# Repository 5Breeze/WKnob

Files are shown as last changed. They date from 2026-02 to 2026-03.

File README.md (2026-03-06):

<div style="font-family:sans-serif;max-width:900px;margin:auto;color:#333;line-height:1.7">

<div style="background:linear-gradient(135deg,#2a9d8f,#264653);padding:32px;border-radius:14px;color:white;text-align:center;margin-bottom:30px">
<h1 style="margin:0">WKnob Wireless Knob</h1>
  

<p style="opacity:0.9;margin-top:4px">BLE · HomeAssistant · BTHome · Encoder · Accelerometer Interaction</p>
</div>

<hr style="border:none;border-top:1px solid #ccc;margin:30px 0" />

<div style="background:#f8f9fa;padding:20px;border-radius:10px;border-left:5px solid #2a9d8f">
<h3 style="color:#2a9d8f;margin-top:0">Introduction</h3>
<p>I’ve long wanted to build a <strong>wireless knob controller</strong>, but off-the-shelf wireless buttons are already very cheap (around ¥10). DIYing a fully enclosed device didn’t seem cost-effective, so the idea was put on hold for a while.</p>
<p>Later, I noticed that <strong>wireless knobs with encoders are actually quite rare</strong>.</p>
<p>That gave me a new idea:<br />
• Add an <strong>encoder knob</strong>,<br />
• Include an <strong>accelerometer</strong>,<br />
• Unlock more <strong>interesting interactive features</strong>.</p>
<p>And so this project was born.</p>
</div>

<hr style="border:none;border-top:1px solid #ccc;margin:30px 0" />

<div style="background:#f8f9fa;padding:16px 18px;border-radius:10px;border-left:5px solid #2a9d8f">
<h3 style="color:#2a9d8f;margin:0 0 10px 0">Project Demo (click to view)</h3>
<div style="text-align:center">
<a href="https://www.bilibili.com/video/BV1ejPszpENa/" target="_blank">

</a>
</div>
</div>

<hr style="border:none;border-top:1px solid #ccc;margin:30px 0" />

<div style="border-left:4px solid #2a9d8f;padding:12px 16px;font-family:system-ui,sans-serif;max-width:800px">
<h3 style="margin:0 0 10px 0;color:#2a9d8f">Features Overview</h3>
<table style="width:100%;border-collapse:collapse;font-size:14px">
<thead>
<tr style="background:#f5f5f5">
<th style="padding:8px;border:1px solid #ddd;width:28%">Interaction</th>
<th style="padding:8px;border:1px solid #ddd">Function Description</th>
</tr>
</thead>
<tbody>
<tr>
<td style="padding:8px;border:1px solid #ddd">🔄 Encoder Knob</td>
<td style="padding:8px;border:1px solid #ddd">Rotation changes encoder value, range <b>-127 ~ +127</b>, supports cyclic counting</td>
</tr>
<tr>
<td style="padding:8px;border:1px solid #ddd">🔘 Single Click</td>
<td style="padding:8px;border:1px solid #ddd">Triggers <b>single-click event</b></td>
</tr>
<tr>
<td style="padding:8px;border:1px solid #ddd">🔘 Double Click</td>
<td style="padding:8px;border:1px solid #ddd">Triggers <b>double-click event</b></td>
</tr>
<tr>
<td style="padding:8px;border:1px solid #ddd">🔘 Triple Click</td>
<td style="padding:8px;border:1px solid #ddd">Triggers <b>triple-click event</b></td>
</tr>
<tr>
<td style="padding:8px;border:1px solid #ddd">⏳ Single Long Press</td>
<td style="padding:8px;border:1px solid #ddd">Triggers <b>single long-press event</b></td>
</tr>
<tr>
<td style="padding:8px;border:1px solid #ddd">⏳ Double Long Press</td>
<td style="padding:8px;border:1px solid #ddd">Triggers <b>double long-press event</b></td>
</tr>
<tr>
<td style="padding:8px;border:1px solid #ddd">⏳ Triple Long Press</td>
<td style="padding:8px;border:1px solid #ddd">Triggers <b>triple long-press event</b></td>
</tr>
<tr>
<td style="padding:8px;border:1px solid #ddd">📐 Hold & Keep Pressing</td>
<td style="padding:8px;border:1px solid #ddd">Enter special mode: read 3‑axis accelerometer data and reset encoder count</td>
</tr>
</tbody>
</table>
</div>

<hr style="border:none;border-top:1px solid #ccc;margin:30px 0" />

<div style="background:#f8f9fa;padding:20px;border-radius:10px;border-left:5px solid #2a9d8f">
<h3 style="color:#2a9d8f;margin-top:0">User Guide</h3>
<div style="background:#ffffff;border:1px solid #eee;padding:18px;border-radius:10px">
<h4>1️⃣ Firmware Flashing</h4>
<p>Flash firmware using the <strong>WCH_TOOL</strong> utility.</p>
<p>Features: simple operation | batch support | suitable for mass production</p>
<p>Firmware file is included in attachments.</p>
<div align="center" style="margin-top:15px">


</div>
</div>

<div style="background:#ffffff;border:1px solid #eee;padding:18px;border-radius:10px">
<h4>2️⃣ Use with HomeAssistant</h4>
<p>After flashing, add the device in <strong>Home Assistant (HA)</strong>.</p>
<p>The device is usually <strong>auto‑discovered</strong> under the name <strong>WKnob</strong>.</p>
<div align="center" style="margin-top:15px">


</div>
<p>Once added, you can view real‑time sensor data, create automations, and link with other HA devices.</p>
<div align="center" style="margin-top:15px">


</div>
</div>
</div>

<hr style="border:none;border-top:1px solid #ccc;margin:30px 0" />

<div style="background:#f8f9fa;padding:20px;border-radius:10px;border-left:5px solid #2a9d8f">
<h3 style="color:#2a9d8f;margin-top:0">Communication Mechanism</h3>
<p>Default strategy:<br />
Idle state: broadcast every 10 seconds<br />
Action triggered: broadcast 10 times per second<br />
Trigger state lasts <strong>2–5 seconds</strong>.<br />
Balances <strong>low power consumption</strong> and <strong>fast response</strong>.</p>
</div>

<hr style="border:none;border-top:1px solid #ccc;margin:30px 0" />

<div style="background:#f8f9fa;padding:18px 20px;border-radius:10px;border-left:4px solid #2a9d8f;font-family:system-ui,sans-serif;max-width:720px">
<h3 style="color:#2a9d8f;margin:0 0 12px 0">Related HA Projects</h3>
<ul style="list-style:none;padding:0;margin:0;line-height:1.6">
<li style="margin-bottom:10px"><b>🔵 HA BLE Door & Light Sensor / LMsensor</b><br /><a href="https://oshwhub.com/bitshen/bthome" style="color:#2a9d8f;text-decoration:none">https://oshwhub.com/bitshen/bthome</a></li>
<li style="margin-bottom:10px"><b>🟣 HA Voice Assistant / AIO</b><br /><a href="https://oshwhub.com/bitshen/esphome-ai" style="color:#2a9d8f;text-decoration:none">https://oshwhub.com/bitshen/esphome-ai</a></li>
<li style="margin-bottom:10px"><b>🟢 HA BLE Thermometer & Hygrometer</b><br /><a href="https://oshwhub.com/bitshen/shi-wai-wen-du-ji_copy" style="color:#2a9d8f;text-decoration:none">https://oshwhub.com/bitshen/shi-wai-wen-du-ji_copy</a></li>
<li style="margin-bottom:10px"><b>🟡 HA Desktop Sensor / CliQ</b><br /><a href="https://oshwhub.com/bitshen/guang-wen-ji-zhuo-mian-bai-jian" style="color:#2a9d8f;text-decoration:none">https://oshwhub.com/bitshen/guang-wen-ji-zhuo-mian-bai-jian</a></li>
<li style="margin-bottom:10px"><b>🟠 HA BLE Gateway VerA</b><br /><a href="https://oshwhub.com/bitshen/esp32-c3-mi-ni-lan-ya-wang-guan_copy" style="color:#2a9d8f;text-decoration:none">https://oshwhub.com/bitshen/esp32-c3-mi-ni-lan-ya-wang-guan_copy</a></li>
<li><b>🔷 HA BLE Gateway VerB</b><br /><a href="https://oshwhub.com/bitshen/esp32-c3-mi-ni-lan-ya-wang-guan_copy_copy" style="color:#2a9d8f;text-decoration:none">https://oshwhub.com/bitshen/esp32-c3-mi-ni-lan-ya-wang-guan_copy_copy</a></li>
</ul>
</div>

<hr style="border:none;border-top:1px solid #ccc;margin:30px 0" />

<div style="background:#f8f9fa;padding:20px;border-radius:10px;border-left:5px solid #2a9d8f">
<h3 style="color:#2a9d8f;margin-top:0">Components & Parts</h3>
<p>SMT encoder — pay attention to height when purchasing</p>


<p>Aluminum alloy knob</p>


<p>Enclosure design in attachments — uses <strong>heat‑set inserts: M3 × 4 × 3</strong></p>
<div style="text-align:center;margin-top:15px">



  

</div>
</div>

<div style="background:#f1f1f1;padding:25px;border-radius:10px;border-left:6px solid #2a9d8f;margin-top:40px">
<p>Afterword —<br />
This is probably <strong>my last project as a student</strong>.<br />
I’m not sure if I’ll still have time for these fun personal projects after graduation. Maybe future projects will only be for work and profit. I’m planning one more keyboard project as a graduation gift this year.<br />
Started well, ended well.</p>
</div>

</div>

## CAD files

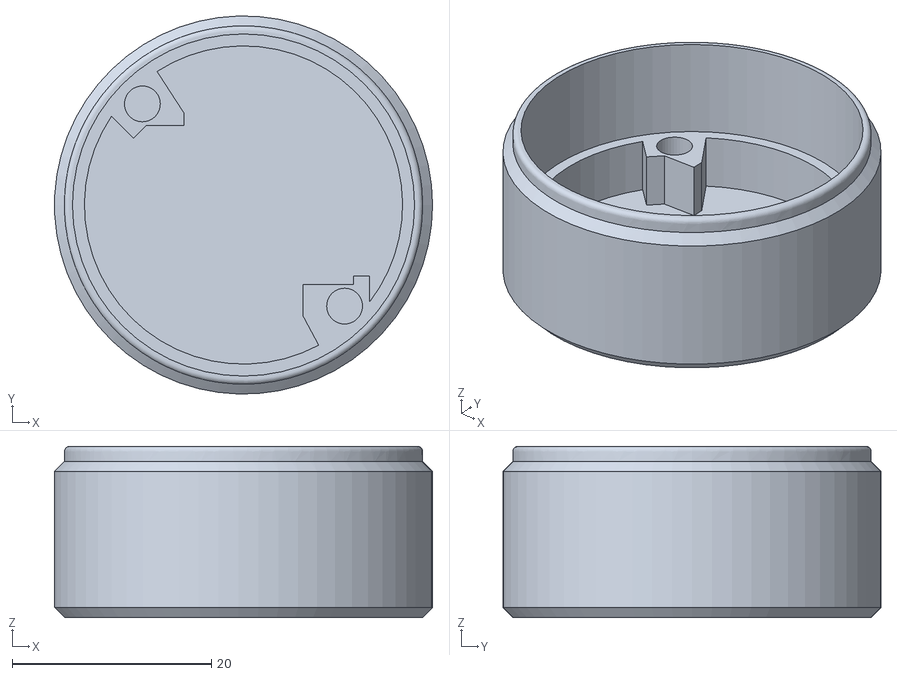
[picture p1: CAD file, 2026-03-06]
B (1).STL
38.0 x 38.0 x 17.2

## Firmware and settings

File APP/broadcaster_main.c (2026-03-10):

/* (C) COPYRIGHT ********************************************************
 * File Name          : main.c
 * Author             : WCH
 * Version            : V1.0
 * Date               : 2020/08/06
 * Description        : 广播应用主入口，完成系统初始化
 *****************************************************************************
 * Copyright (c) 2021 Nanjing Qinheng Microelectronics Co., Ltd.
 * Attention: This software (modified or not) and binary are used for
 * microcontroller manufactured by Nanjing Qinheng Microelectronics.
 *****************************************************************************/

/******************************************************************************/
/* 头文件包含 */
#include "CONFIG.h"
#include "HAL.h"
#include "broadcaster.h"

/*********************************************************************
 * GLOBAL TYPEDEFS
 */
__attribute__((aligned(4))) uint32_t MEM_BUF[BLE_MEMHEAP_SIZE / 4];

#if (defined(BLE_MAC)) && (BLE_MAC == TRUE)
const uint8_t MacAddr[6] = { 0x84, 0xC2, 0xE4, 0x03, 0x02, 0x02 };
#endif

/*********************************************************************
 * @fn      Main_Circulation
 *
 * @brief   主循环
 *
 * @return  none
 */
__HIGH_CODE
__attribute__((noinline)) void Main_Circulation()
{
    while (1) {
        TMOS_SystemProcess();
    }
}

/*********************************************************************
 * @fn      main
 *
 * @brief   程序入口
 *
 * @return  none
 */
int main(void)
{
#if (defined(DCDC_ENABLE)) && (DCDC_ENABLE == TRUE)
    PWR_DCDCCfg(ENABLE);
#endif
    SetSysClock(CLK_SOURCE_PLL_60MHz);
#if (defined(HAL_SLEEP)) && (HAL_SLEEP == TRUE)
    GPIOA_ModeCfg(GPIO_Pin_All, GPIO_ModeIN_PU);
    GPIOB_ModeCfg(GPIO_Pin_All, GPIO_ModeIN_PU);
#endif
#ifdef DEBUG
    GPIOA_SetBits(bTXD1);
    GPIOA_ModeCfg(bTXD1, GPIO_ModeOut_PP_5mA);
    UART1_DefInit();
#endif
    /* 配置外部中断源为 GPIO - PB10-13 */
    // //PB13-ACC
    GPIOB_ModeCfg(GPIO_Pin_13, GPIO_ModeIN_Floating);
    // GPIOB_ITModeCfg(GPIO_Pin_13, GPIO_ITMode_FallEdge); // 下降沿触发
    //PB12-ECK
    GPIOB_ModeCfg(GPIO_Pin_12, GPIO_ModeIN_Floating);
    GPIOB_ITModeCfg(GPIO_Pin_12, GPIO_ITMode_FallEdge); // 下降沿触发
    //PB11-ECL
    GPIOB_ModeCfg(GPIO_Pin_11, GPIO_ModeIN_Floating);
    GPIOB_ITModeCfg(GPIO_Pin_11, GPIO_ITMode_FallEdge); // 下降沿触发
    //PB10-ECR
    GPIOB_ModeCfg(GPIO_Pin_10, GPIO_ModeIN_Floating);
    GPIOB_ITModeCfg(GPIO_Pin_10, GPIO_ITMode_FallEdge); // 下降沿触发

    PFIC_EnableIRQ(GPIO_B_IRQn);
    PWR_PeriphWakeUpCfg(ENABLE, RB_SLP_GPIO_WAKE, RB_SLP_GPIO_WAKE);

    mDelaymS(100);  // 给电容充电、电源稳定时间
    // PRINT("%s\n", VER_LIB);
    CH59x_BLEInit();
    HAL_Init();
    GAPRole_BroadcasterInit();
    Broadcaster_Init();
    Main_Circulation();
}

//中断服务函数
__INTERRUPT
__HIGH_CODE
void GPIOB_IRQHandler( void )
{
    // // 检测到PB12中断
    // if(GPIOB_ReadITFlagBit(GPIO_Pin_13))
    // {
    //     PRINT("ENTER ACC_IRQHandler\n");
    //     tmos_set_event(Broadcaster_TaskID, ACC_SET_EVENT); // 触发加速度事件
    //     GPIOB_ClearITFlagBit(GPIO_Pin_13);
    // } 
if (GPIOB_ReadITFlagBit(GPIO_Pin_12))
{
    mDelaymS(5); // 简单消抖
    uint8_t level = GPIOB_ReadPortPin(GPIO_Pin_12) ? 1 : 0;
    if (!level) { // 低电平 = 按下（假设按下接地）
        tmos_set_event(Broadcaster_TaskID, ECK_SET_EVENT);
    } else {      // 高电平 = 松开
        tmos_set_event(Broadcaster_TaskID, ECK_RELEASE_EVENT);
    }
        // 切换到相反边沿，下次捕捉另一个动作
    GPIOB_ITModeCfg(GPIO_Pin_12,
        level ? GPIO_ITMode_FallEdge : GPIO_ITMode_RiseEdge);
    GPIOB_ClearITFlagBit(GPIO_Pin_12);
}

else if (GPIOB_ReadITFlagBit(GPIO_Pin_10))
{
    tmos_set_event(Broadcaster_TaskID, ECN_SET_EVENT);
    // 根据当前电平动态切换触发边沿，模拟双边沿检测
    GPIOB_ITModeCfg(GPIO_Pin_10,
    GPIOB_ReadPortPin(GPIO_Pin_10) ? GPIO_ITMode_FallEdge : GPIO_ITMode_RiseEdge);
    GPIOB_ClearITFlagBit(GPIO_Pin_10);
}
else if (GPIOB_ReadITFlagBit(GPIO_Pin_11))
{
    tmos_set_event(Broadcaster_TaskID, ECN_SET_EVENT);
    // 根据当前电平动态切换触发边沿，模拟双边沿检测
    GPIOB_ITModeCfg(GPIO_Pin_11,
    GPIOB_ReadPortPin(GPIO_Pin_11) ? GPIO_ITMode_FallEdge : GPIO_ITMode_RiseEdge);
    GPIOB_ClearITFlagBit(GPIO_Pin_11);
}
}


/******************************** endfile @ main ******************************/

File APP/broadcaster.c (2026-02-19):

/* (C) COPYRIGHT ********************************************************
 * File Name          : broadcaster.c
 * Author             : WCH
 * Version            : V1.0
 * Date               : 2020/08/06
 * Description        : 广播应用程序，初始化广播参数后持续广播
 *
 *****************************************************************************
 * Copyright (c) 2021 Nanjing Qinheng Microelectronics Co., Ltd.
 * Attention: This software (modified or not) and binary are used for
 * microcontroller manufactured by Nanjing Qinheng Microelectronics.
 *****************************************************************************/

#include "CONFIG.h"
#include "devinfoservice.h"
#include "broadcaster.h"
#include "app_i2c.h"
#include <stdint.h>
#include <stdio.h>
#include <math.h>

// 广播间隔 (单位: 625us, 最小值为160=100ms)
#define DEFAULT_ADVERTISING_INTERVAL (1600 * 10) // 4s
#define FAST_ADVERTISING_INTERVAL (1600 / 10) // 0.1s
// 电池定时事件周期
#define SBP_PERIODIC_EVT_PERIOD (1600 * 60 * 10) // 10min

// ADC 粗略校准值
static signed short RoughCalib_Value = 0;
// 电池电压
static uint16_t bat = 0;

uint8_t mag_int_flag = 0;
uint8_t eck_int_flag = 0;
uint8_t ecr_int_flag = 0;
uint8_t ecl_int_flag = 0;

int8_t ecc_count = 0;

// Task ID for internal task/event processing
uint8_t Broadcaster_TaskID;

#define BAT_OFFSET 9
#define ACCX_OFFSET 11
#define ACCY_OFFSET 14
#define ACCZ_OFFSET 17
#define COUNT_OFFSET 20
#define BTN_OFFSET 22 // 新增 button 事件偏移

static uint8_t advertData[] = {
    // AD结构1: Flags (3字节)
    0x02,
    GAP_ADTYPE_FLAGS,
    GAP_ADTYPE_FLAGS_GENERAL | GAP_ADTYPE_FLAGS_BREDR_NOT_SUPPORTED,

    // AD结构2: BTHome Service Data
    // length = 后面字节数：1(UUID低)+1(UUID高)+1(device info)+
    //          2(bat)+3(accx)+3(accy)+3(accz)+2(count)+2(button) = 18 = 0x12
    // 但AD length字段含自身后的所有字节，格式是 len, 0x16, uuid_lo, uuid_hi, payload...
    // len = 1(0x16) + 2(uuid) + payload_len = 3 + 15 = 18 = 0x13
    0x13,
    0x16,
    0xD2,
    0xFC,
    0x40, // BTHome v2 device info

    0x01,
    0x64, // [9]  battery %
    0x51,
    0x00,
    0x00, // [11] ACCx (obj 0x51, uint16)
    0x51,
    0x00,
    0x00, // [14] ACCy
    0x51,
    0x00,
    0x00, // [17] ACCz
    0x59,
    0x00, // [20] rotation (obj 0x59, int8)
    0x3A,
    0x00, // [22] button event (obj 0x3A, uint8), 0x00=None

    // AD结构3: 完整本地名称
    0x06,
    GAP_ADTYPE_LOCAL_NAME_COMPLETE,
    'W',
    'K',
    'n',
    'o',
    'b',
};
/*
 * 本地函数声明
 */
static void Broadcaster_ProcessTMOSMsg(tmos_event_hdr_t* pMsg);
static void Broadcaster_StateNotificationCB(gapRole_States_t newState);
extern bStatus_t GAP_UpdateAdvertisingData(uint8_t taskID, uint8_t adType, uint16_t dataLen, uint8_t* pAdvertData);

/*
 * PROFILE CALLBACKS
 */

// GAP Role 回调
static gapRolesBroadcasterCBs_t Broadcaster_BroadcasterCBs = {
    Broadcaster_StateNotificationCB, // Profile State Change Callbacks
    NULL
};

/*
 * PUBLIC FUNCTIONS
 */

// 采样电池电压
__HIGH_CODE
uint16_t sample_battery_voltage()
{
    // VINA 实际电压值 1050=1.05V
    const int vref = 1050;

    ADC_InterBATSampInit();

    // 每200次进行一次粗略校准
    static uint8_t calib_count = 0;
    calib_count++;
    if (calib_count == 1) {
        RoughCalib_Value = ADC_DataCalib_Rough();
    }
    calib_count %= 200;

    ADC_ChannelCfg(CH_INTE_VBAT);
    return (ADC_ExcutSingleConver() + RoughCalib_Value) * vref / 512 - 3 * vref;
}

#define VOLTAGE_BUFFER_SIZE 10

typedef struct {
    uint16_t voltage_x100; // 100倍电压，单位0.01V
    uint8_t percentage; // 对应电量
} VoltageLevel;

const VoltageLevel voltage_map[] = {
    { 180, 1 },
    { 185, 5 },
    { 190, 8 },
    { 192, 10 },
    { 195, 12 },
    { 200, 15 },
    { 205, 17 },
    { 210, 18 },
    { 215, 19 },
    { 220, 20 },
    { 225, 25 },
    { 230, 30 },
    { 232, 35 },
    { 235, 40 },
    { 240, 45 },
    { 245, 50 },
    { 250, 55 },
    { 255, 60 },
    { 257, 65 },
    { 260, 70 },
    { 262, 75 },
    { 265, 80 },
    { 270, 85 },
    { 275, 88 },
    { 280, 90 },
    { 285, 93 },
    { 290, 95 },
    { 295, 98 },
    { 300, 100 }
};

#define LEVEL_COUNT (sizeof(voltage_map) / sizeof(VoltageLevel))

// 电压转换为电量百分比
uint8_t voltage_to_percentage(uint16_t voltage_x100)
{
    if (voltage_x100 < voltage_map[0].voltage_x100)
        return 0;

    for (int i = 1; i < LEVEL_COUNT; ++i) {
        if (voltage_x100 < voltage_map[i].voltage_x100) {
            return voltage_map[i - 1].percentage;
        }
    }
    return voltage_map[LEVEL_COUNT - 1].percentage;
}

// 主函数接口
uint8_t get_battery_percentage(uint16_t new_voltage_x100)
{
    static uint16_t voltage_buffer[VOLTAGE_BUFFER_SIZE] = { 0 };
    static uint8_t voltage_count = 0;
    static uint8_t buffer_index = 0;
    static int last_percentage = 100;

    // 存入缓冲区
    voltage_buffer[buffer_index] = new_voltage_x100;
    buffer_index = (buffer_index + 1) % VOLTAGE_BUFFER_SIZE;
    if (voltage_count < VOLTAGE_BUFFER_SIZE)
        voltage_count++;

    // 求均值（整数求和）
    uint32_t sum = 0;
    for (uint8_t i = 0; i < voltage_count; ++i) {
        sum += voltage_buffer[i];
    }
    uint16_t avg_voltage = sum / voltage_count;

    // 查表转换为电量百分比
    uint8_t percentage = voltage_to_percentage(avg_voltage);

    // 电量不允许回升
    if (percentage > last_percentage)
        percentage = last_percentage;

    last_percentage = percentage;
    return percentage;
}

#define LIS2DW12_ADDR 0x19 // 若SA0接VDD，否则为0x18
#define LIS2DW12_ADDR 0x19 // 若SA0接VDD，否则为0x18

#define REG_CTRL1 0x20
#define REG_CTRL2 0x21
#define REG_CTRL3 0x22
#define TAR4_INT1_PAD_CTRL 0x23
#define REG_CTRL5_INT2_PAD_CTRL 0x24
#define REG_CTRL6 0x25
#define REG_STATUS 0x27

#define REG_TAP_THS_X 0x30
#define REG_TAP_THS_Y 0x31
#define REG_TAP_THS_Z 0x32
#define REG_INT_DUR 0x33
#define REG_WAKE_UP_THS 0x34
#define REG_TAP_SRC 0x39

#define REG_WHO_AM_I 0x0F

#define REG_OUT_X_L 0x28
#define REG_OUT_X_H 0x29
#define REG_OUT_Y_L 0x2A
#define REG_OUT_Y_H 0x2B
#define REG_OUT_Z_L 0x2C
#define REG_OUT_Z_H 0x2D
#define REG_CTRL7 0x3F

__HIGH_CODE
int lis2dw12_write_reg(uint8_t reg, uint8_t value)
{
    uint8_t buf[2] = { reg, value };
    return i2c_write_to(LIS2DW12_ADDR, buf, 2, 1, 1);
}

__HIGH_CODE
int lis2dw12_read_reg(uint8_t reg, uint8_t* buf, uint8_t len)
{
    if (i2c_write_to(LIS2DW12_ADDR, &reg, 1, 1, 0) != 0) {
        return -1;
    }
    if (i2c_read_from(LIS2DW12_ADDR, buf, len, 1, 100) != 0) {
        return -1;
    }
    return 1;
}

void LIS2DW12_Init(void)
{
    i2c_app_init(LIS2DW12_ADDR); // 重新初始化I2C，确保通信正常
    lis2dw12_write_reg(REG_CTRL1, 0x18); // 配置CTRL1: 低功耗模式1 + 单次转换模式
    lis2dw12_write_reg(REG_CTRL3, 0x02); // 配置CTRL3: 使能软件触发 (SLP_MODE_SEL=1)
    lis2dw12_write_reg(REG_CTRL6, 0x00); // 配置CTRL6: ±2g满量程, 禁用低噪声模式
}

__HIGH_CODE
void update_advert_data()
{
    static uint16_t bl_bat, ad_bat;
    bl_bat = sample_battery_voltage();
    ad_bat = get_battery_percentage(bl_bat / 10);
    advertData[BAT_OFFSET] = ad_bat;
}
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
